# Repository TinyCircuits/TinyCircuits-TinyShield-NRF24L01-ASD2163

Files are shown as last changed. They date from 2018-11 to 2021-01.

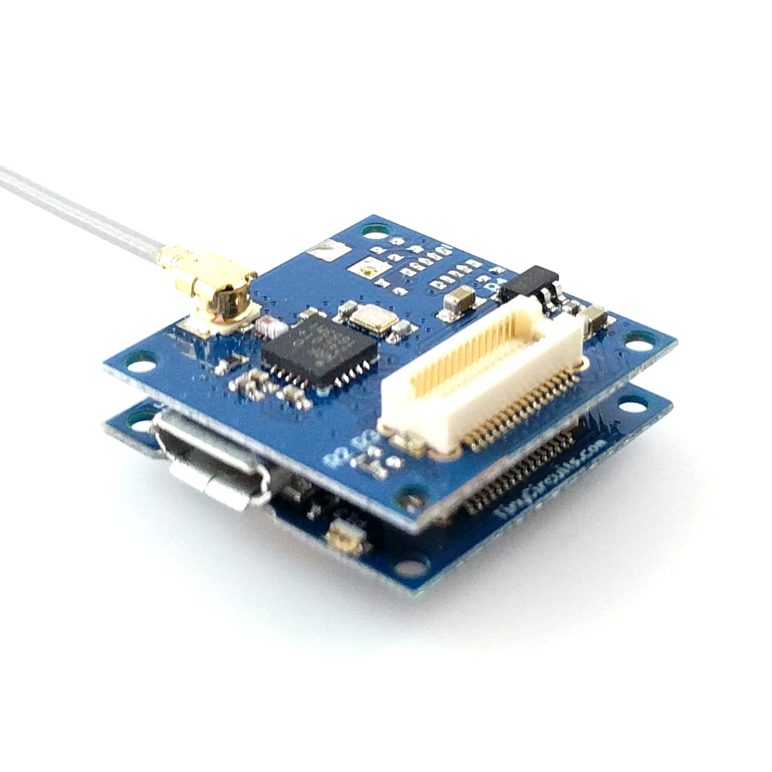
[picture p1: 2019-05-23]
images/ASD2163-R-Tutorial-Image-03.jpg

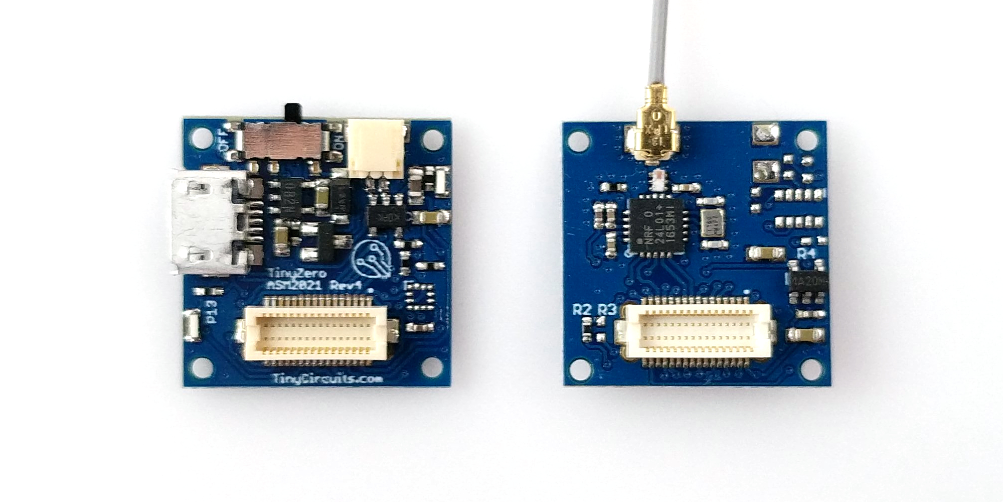
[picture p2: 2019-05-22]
images/ASD2163-R-Tutorial-Image-02.jpg

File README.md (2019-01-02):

# TinyCircuits TinyShield NRF24L01+ Radio Board
# ASD2613 Rev3

These are the design files for the TinyCircuits ASD2163 Rev3 PCB.  This is a TinyShield board that has a Nordic Semiconductor NRF24L01+ 2.4GHZ  chipset, local power supply and level shifters to connect between the TinyDuino and the radio transceiver. 

Format is in Cadsoft Eagle format - Eagle version 6.2 was used for the original design.

For more infomation on this, check out the product page at TinyCircuits.com:  https://tinycircuits.com/products/nrf24-2-4ghz-radio-tinyshieldc.html

# License:

Design by TinyCircuits.
All design files are released under the Creative Commons Attribution Share-Alike 3.0 License, see the following link for details: http://creativecommons.org/licenses/by-sa/3.0

All text above must be included in any redistribution or derived design

This project uses designs and concepts developed as part of the Arduino project and the LilyPad project.  The TinyCircuits design files themselves (schematics, PCB and libraries) are not directly derived from these works' design files and have been created new, however the concepts and basic architecture behind the TinyDuino and TinyLily products are derived and we thank the hard work of the organizations below for their contributions to open-source hardware:
  
Original Arduino Uno Design by Team Arduino

LilyPad Arduino Design by Leah Buechley and Sparkfun Electronics

Please support the open-source hardware community

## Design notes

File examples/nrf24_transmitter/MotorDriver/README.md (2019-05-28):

# TinyCircuits Dual Motor Driver Arduino Library

This library is intended for use with TinyCircuits' ASD2302 Dual Motor Driver TinyShield and ASD2303 Servo Controller Tinyshield. These shields use a ATtiny841 microcontroller with firmware that allows the 16 bit PWM outputs to be controlled through I2c. The Arduino library itself allows for easy interface using the TinyDuino platform. Included with the library is the ATtiny841 firmware- it is intended to be hackable and allow for extra functionality to be implemented(full ATtiny register access through I2C).

## Basic Example

Example programs are included that show how to drive motors or servos from the TinyDuino.

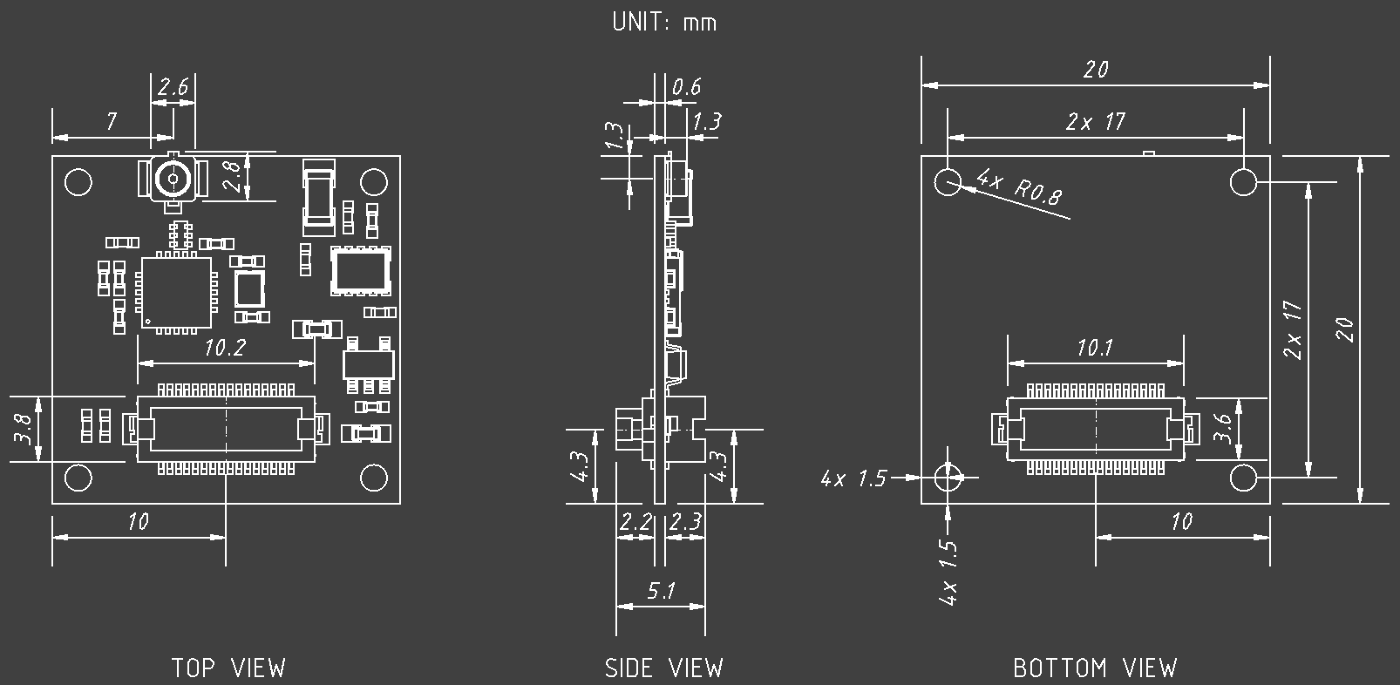
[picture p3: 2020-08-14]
cad/TinyShield_NRF24L01_ASD2163_REV3-DETAILED_DRAWING_COMPACT-PNG.png

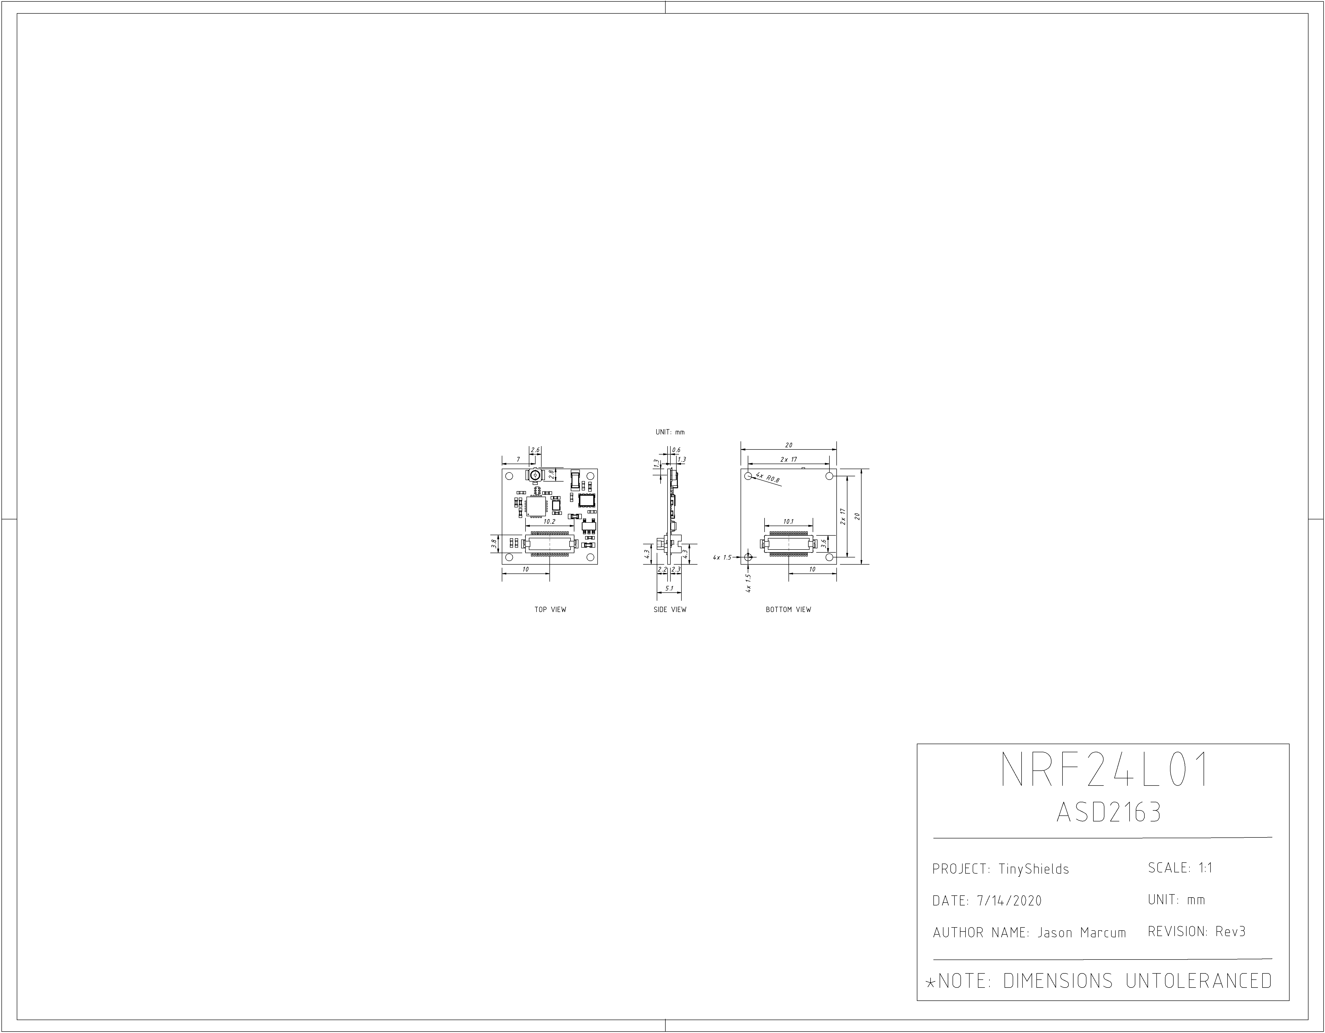
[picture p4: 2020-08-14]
cad/TinyShield_NRF24L01_ASD2163_REV3-DETAILED_DRAWING-PNG.png

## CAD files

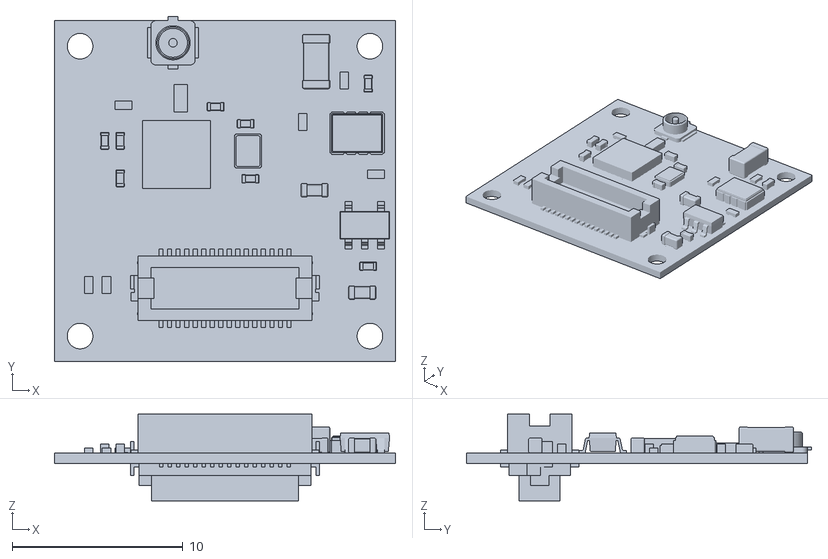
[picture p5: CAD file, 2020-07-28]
cad/TinyShield_NRF24L01_ASD2163_REV3-STL.stl
20.0 x 20.2 x 5.10

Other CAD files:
cad/TinyShield_NRF24L01_ASD2163_REV3-DETAILED_DRAWING-DXF.dxf

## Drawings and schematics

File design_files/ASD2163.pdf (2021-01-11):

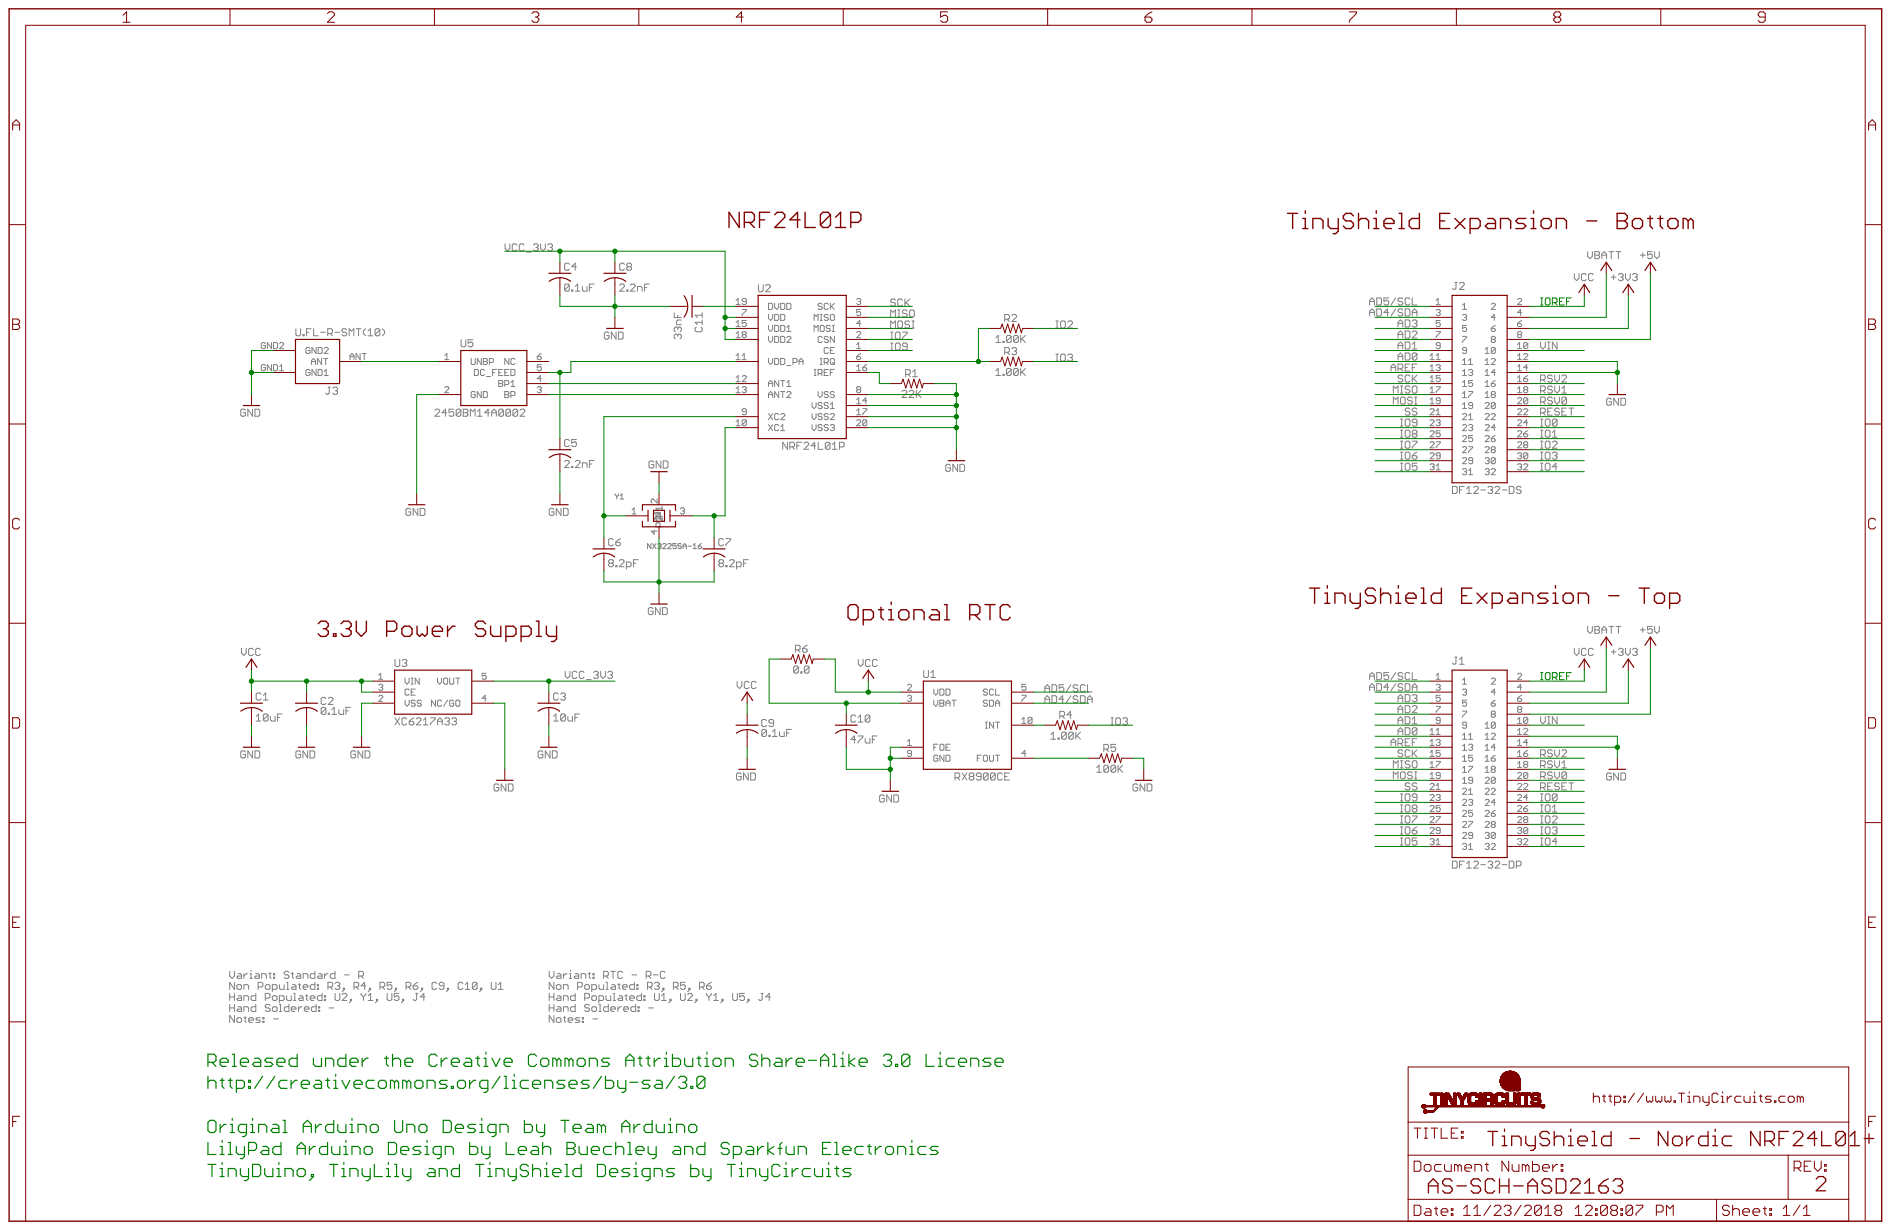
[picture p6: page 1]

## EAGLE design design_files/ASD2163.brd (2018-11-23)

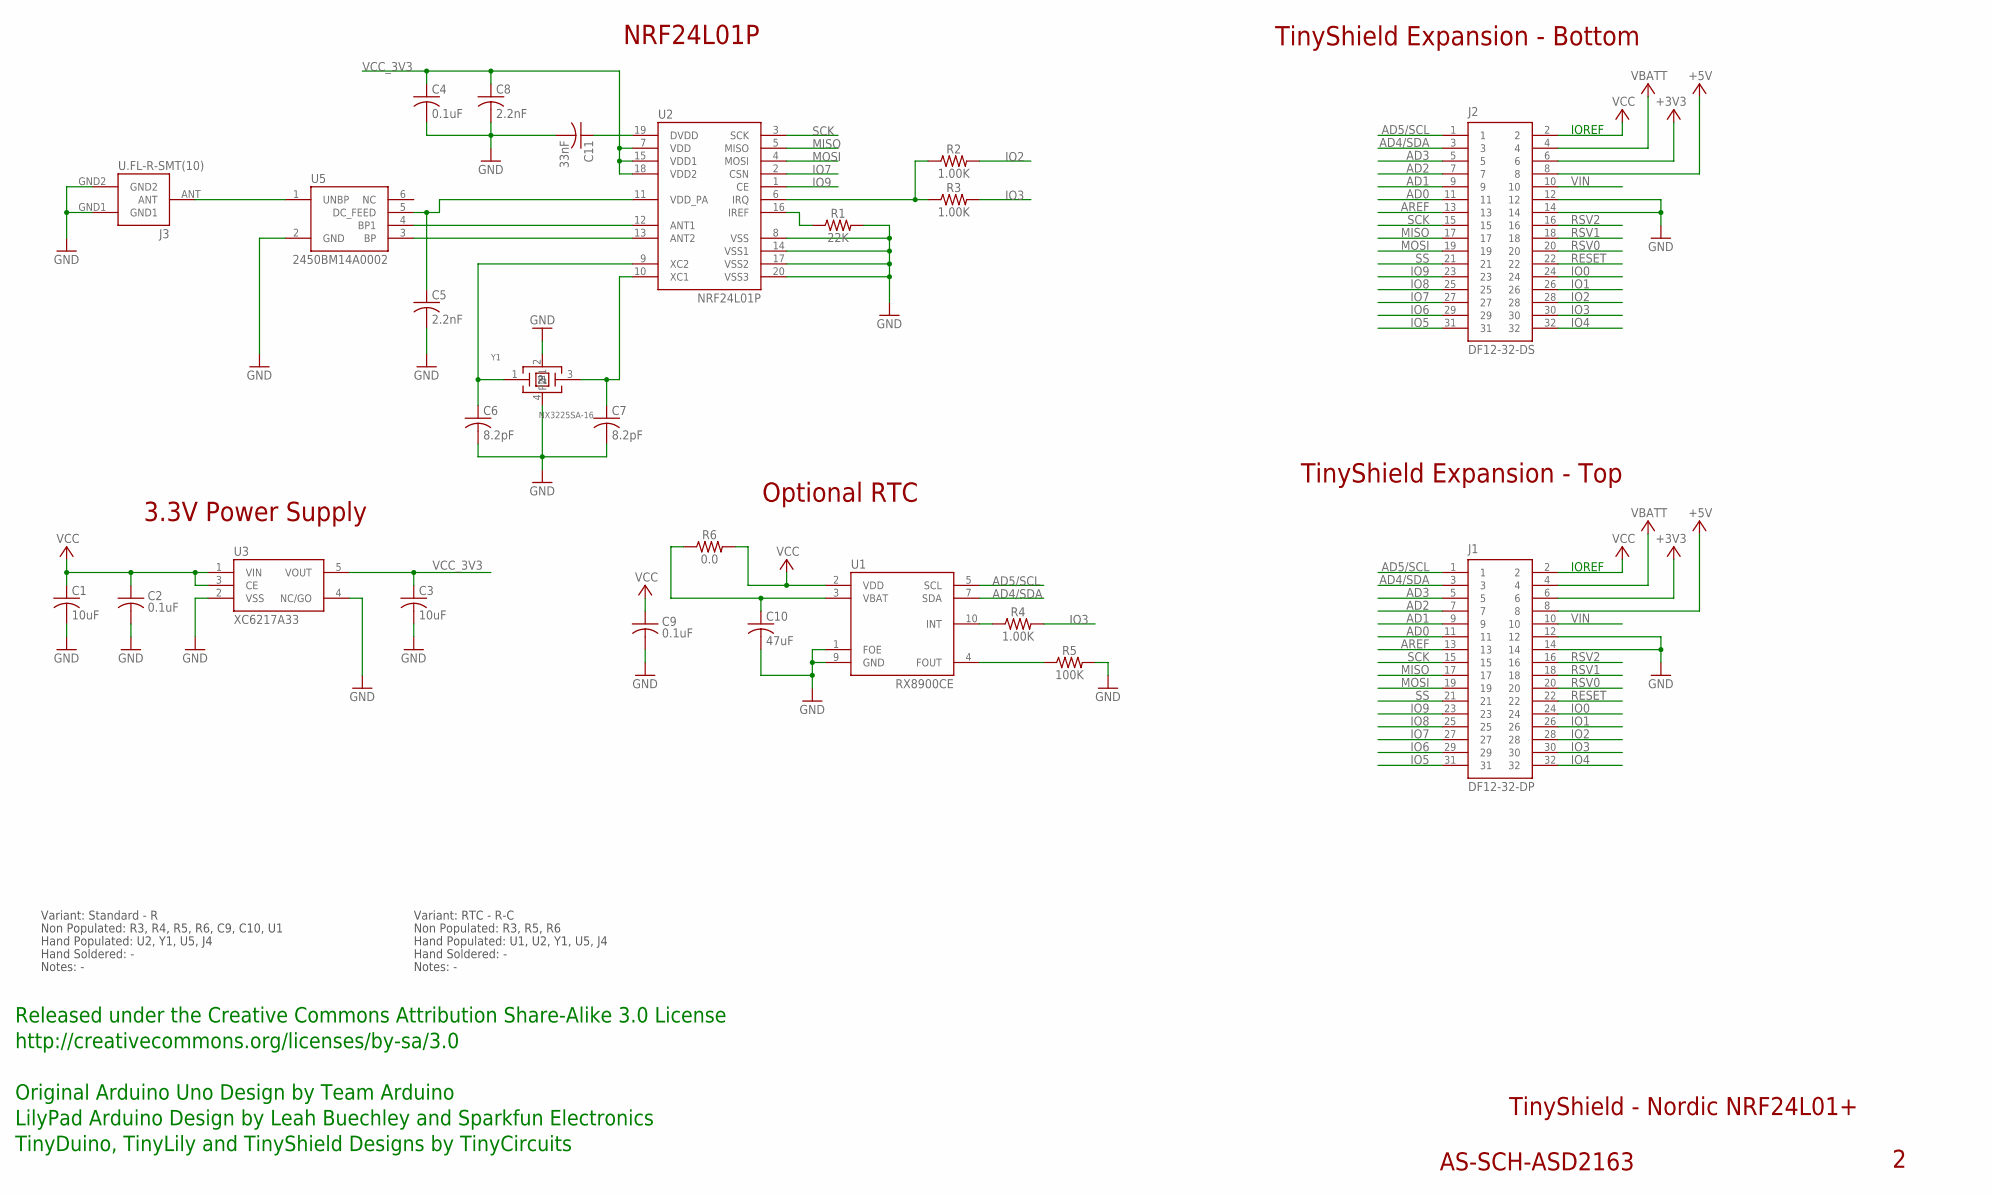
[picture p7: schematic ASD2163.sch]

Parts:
C1, C3: 10uF; C0603; PARTNO AS-ITM-00002
C2, C4, C9: 0.1uF; C0402; PARTNO AS-ITM-00008
C5: 2.2nF; C0402
C6, C7: 8.2pF; C0402; PARTNO AS-ITM-00247
C8: 2.2nF; C0402; PARTNO AS-ITM-00085
C10: 47uF; C1206
C11: 33nF; C0402; PARTNO AS-ITM-00248
J1: DF12-32-DP; PARTNO AS-ITM-00015
J2: DF12-32-DS; PARTNO AS-ITM-00012
J3: U.FL-R-SMT(10)
R1: 22K; 0402
R2, R3, R4: 1.00K; 0402; PARTNO AS-ITM-00003
R5: 100K; 0402
R6: 0.0; 0402; PARTNO AS-ITM-00076
U1: RX8900CE
U2: NRF24L01P; QFN20-NO_PAD
U3: XC6217A33; SOT-25; PARTNO AS-ITM-00249
U5: 2450BM14A0002
Y1: NX3225SA-16; ABM11; PARTNO AS-ITM-00228

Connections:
+3V3: J1.6, J2.6
+5V: J1.8, J2.8
AD0: J1.11, J2.11
AD1: J1.9, J2.9
AD2: J1.7, J2.7
AD3: J1.5, J2.5
AD4/SDA: J1.3, J2.3, U1.7 (SDA)
AD5/SCL: J1.1, J2.1, U1.5 (SCL)
AREF: J1.13, J2.13
GND: C1.2, C2.2, C3.2, C4.2, C5.2, C6.2, C7.2, C8.2, C9.2, C10.2, C11.2, J1.12, J1.14, J2.12, J2.14, J3.GND1, J3.GND2, R1.2, R5.2, U1.1 (FOE), U1.9 (GND), U2.8 (VSS), U2.14 (VSS1), U2.17 (VSS2), U2.20 (VSS3), U3.2 (VSS), U3.4 (NC/GO), U5.2 (GND), Y1.2, Y1.4 (P1)
IO0: J1.24, J2.24
IO1: J1.26, J2.26
IO2: J1.28, J2.28, R2.2
IO3: J1.30, J2.30, R3.2, R4.2
IO4: J1.32, J2.32
IO5: J1.31, J2.31
IO6: J1.29, J2.29
IO7: J1.27, J2.27, U2.2 (CSN)
IO8: J1.25, J2.25
IO9: J1.23, J2.23, U2.1 (CE)
MISO: J1.17, J2.17, U2.5 (MISO)
MOSI: J1.19, J2.19, U2.4 (MOSI)
unnamed: R1.1, U2.16 (IREF)
unnamed: C6.1, U2.9 (XC2), Y1.1
unnamed: J3.ANT, U5.1 (UNBP)
unnamed: C10.1, R6.1, U1.3 (VBAT)
unnamed: C11.1, U2.19 (DVDD)
unnamed: U2.13 (ANT2), U5.3 (BP)
unnamed: U2.12 (ANT1), U5.4 (BP1)
unnamed: C5.1, U2.11 (VDD_PA), U5.5 (DC_FEED)
unnamed: C7.1, U2.10 (XC1), Y1.3 (2)
unnamed: R5.1, U1.4 (FOUT)
RDYN: R2.1, R3.1, U2.6 (IRQ)
RDYN1: R4.1, U1.10 (INT)
RESET: J1.22, J2.22
RSV0: J1.20, J2.20
RSV1: J1.18, J2.18
RSV2: J1.16, J2.16
SCK: J1.15, J2.15, U2.3 (SCK)
SS: J1.21, J2.21
VBATT: J1.4, J2.4
VCC: C1.1, C2.1, C9.1, J1.2, J2.2, R6.2, U1.2 (VDD), U3.1 (VIN), U3.3 (CE)
VCC_3V3: C3.1, C4.1, C8.1, U2.7 (VDD), U2.15 (VDD1), U2.18 (VDD2), U3.5 (VOUT)
VIN: J1.10, J2.10

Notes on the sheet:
TinyShield Expansion - Bottom
TinyShield - Nordic NRF24L01+
AS-SCH-ASD2163
TinyShield Expansion - Top
IOREF
Released under the Creative Commons Attribution Share-Alike 3.0 License
http://creativecommons.org/licenses/by-sa/3.0
LilyPad Arduino Design by Leah Buechley and Sparkfun Electronics
TinyDuino, TinyLily and TinyShield Designs by TinyCircuits
Original Arduino Uno Design by Team Arduino
3.3V Power Supply
NRF24L01P
Optional RTC
Non Populated: R3, R4, R5, R6, C9, C10, U1
Hand Populated: U2, Y1, U5, J4
Hand Soldered: -
Notes: -
Variant: Standard - R
Non Populated: R3, R5, R6
Hand Populated: U1, U2, Y1, U5, J4
Variant: RTC - R-C

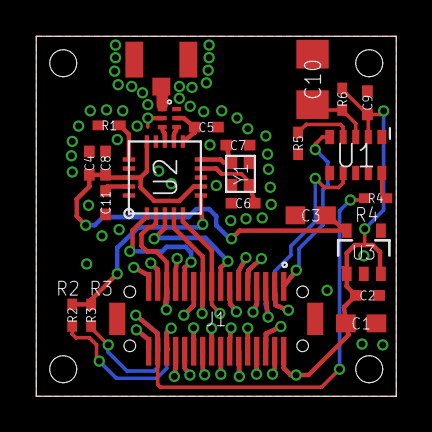
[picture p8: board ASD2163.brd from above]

Board: 2 copper layers, 20.0 x 20.0 mm, 26 parts (1 on the bottom side), 44 nets.

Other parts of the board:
U$1: DOCFIELD-TINYCIRCUITS-PCB

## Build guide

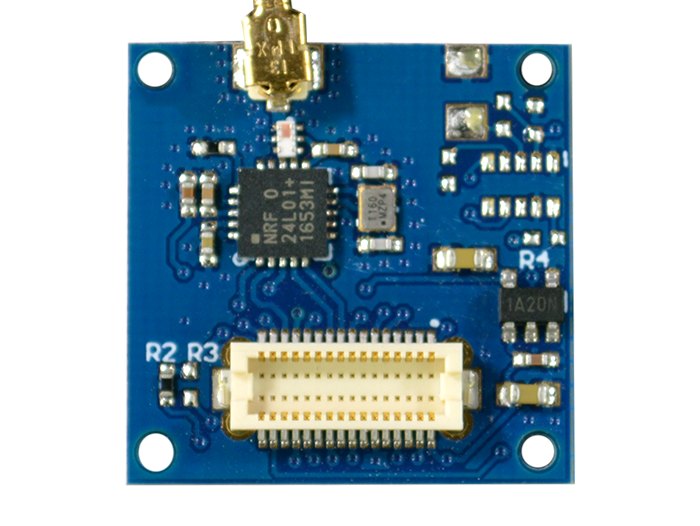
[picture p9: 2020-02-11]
images/ASD2163-R-Tutorial-Image-01.png

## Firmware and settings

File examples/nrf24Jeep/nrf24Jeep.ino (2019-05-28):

#define use433 0


#include <Wire.h>
#include <SPI.h>
#include <RH_NRF24.h>
#include <RH_RF22.h>
#include "RTIMUSettings.h"
#include "RTIMU.h"
#include "RTFusionRTQF.h"
#include "CalLib.h"

RTIMU *imu;                                           // the IMU object
RTFusionRTQF fusion;                                  // the fusion object
RTIMUSettings settings;                               // the settings object


#include <MotorDriver.h>
#include <ServoDriver.h>

MotorDriver motor(NO_R_REMOVED);
ServoDriver servo(R1_REMOVED);

#if(use433)
RH_RF22 nrf24(7, 3);
#else
RH_NRF24 nrf24(9, 7);
#endif

long timeout = 1000;
long lastcommand = 0;

int servoHold = 2000;
int servoRelease = 1000;

int maxPWM = 500;

#if defined (ARDUINO_ARCH_AVR)
#define SerialMonitorInterface Serial
#elif defined(ARDUINO_ARCH_SAMD)
#define SerialMonitorInterface SerialUSB
#endif


void setup()
{
  SerialUSB.begin(115200);
  //while (!SerialUSB);
  Wire.begin();

#if(use433)
  nrf24.init();
  nrf24.setTxPower(RH_RF22_TXPOW_20DBM);
  nrf24.setModemConfig(RH_RF22::GFSK_Rb125Fd125);//GFSK_Rb4_8Fd45?
#else
  nrf24.init();
  nrf24.setChannel(1);
  nrf24.setRF(RH_NRF24::DataRate250kbps, RH_NRF24::TransmitPower0dBm);
#endif


  if ( motor.begin(500)) {
    SerialMonitorInterface.println("Motor driver not detected!");
    //while (1);
  }
  motor.setMotor(1, 0);
  motor.setMotor(2, 0);
  if (servo.begin(20000)) {    //Set the period to 20000us or 20ms, correct for driving most servos
    SerialMonitorInterface.println("Servo driver not detected!");
    //while (1);
  }
  servo.begin(5000);
  servo.setServo(1, 1500);

  /*
    Wire.beginTransmission(0x70);
    Wire.write(0x04 + 0);
    Wire.endTransmission();
  */
  motor.setFailsafe(100);
  imu = RTIMU::createIMU(&settings);
  imu->IMUInit();
  fusion.setGyroEnable(true);
  fusion.setAccelEnable(true);
}

int currentXdata = 0;
int currentYdata = 0;

int setPoint = 512;
int in = 0;
int lastPWM = 0;

void loop()
{
  if (imu->IMURead()) {                                // get the latest data if ready yet
    fusion.newIMUData(imu->getGyro(), imu->getAccel(), imu->getCompass(), imu->getTimestamp());
    currentXdata = fusion.getFusionPose().x() * RTMATH_RAD_TO_DEGREE;
    currentYdata = -fusion.getFusionPose().y() * RTMATH_RAD_TO_DEGREE;
    //SerialUSB.print(currentXdata);
    //SerialUSB.print('\t');
    //SerialUSB.println(currentYdata);
    
  }
  if (nrf24.available())
  {
    // Should be a message for us now
    uint8_t buf[32];
    uint8_t len = sizeof(buf);
    if (nrf24.recv(buf, &len) && buf[0] == 5)
    {
      lastcommand = millis();
      int16_t LY = buf[1] << 8 | buf[2];
      int16_t RY = buf[3] << 8 | buf[4];
      int16_t LX = buf[5] << 8 | buf[6];
      int16_t RX = buf[7] << 8 | buf[8];

      if (abs(LY) < 50) {
        LY = 0;
      }
      //motor.setMotor(1, constrain(-LY, -500, 500));
      servo.setServo(1, 1500 - 75 + constrain(1.1 * -(float)RX, -600, 500));

      motor.setMotor(1, constrain(-RY, -500, 500));
      motor.setMotor(2, constrain(LY, -500, 500));


      int voltage = getVCClevel();
      uint8_t data[8];
      data[0] = 5;
      data[1] = abs(0);
      data[2] = voltage >> 8;
      data[3] = voltage;
      data[4] = currentXdata >> 8;
      data[5] = currentXdata;
      data[6] = currentYdata >> 8;
      data[7] = currentYdata;
      nrf24.send(data, 8);
      nrf24.waitPacketSent();
      nrf24.sleep();
    }
  }
  if (millis() > lastcommand + timeout) {
    //digitalWrite(13,LOW);
    motor.setMotor(1, 0);
    motor.setMotor(2, 0);
    lastcommand = millis();
  }

}

int getVCClevel() {
  //http://forum.arduino.cc/index.php?topic=133907.0
  const long InternalReferenceVoltage = 1100L;
  /*ADMUX = (0<<REFS1) | (1<<REFS0) | (0<<ADLAR) | (1<<MUX3) | (1<<MUX2) | (1<<MUX1) | (0<<MUX0);
    delay(1);
    ADCSRA |= _BV( ADSC );
    while( ( (ADCSRA & (1<<ADSC)) != 0 ) );
    int result = (((InternalReferenceVoltage * 1024L) / ADC) + 5L) / 10L;*/
  return 1;//this should be in hundredths of a volt
}

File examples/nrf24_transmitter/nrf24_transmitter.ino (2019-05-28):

#define use433 0

#include <Wire.h>
#include <SPI.h>
#include <RH_NRF24.h>
#include <RH_RF22.h>
#include <TinyScreen.h>

#define	BLACK           0x00
#define	BLUE            0xE0
#define	RED             0x03
#define	GREEN           0x1C
#define	DGREEN           0x0C
#define YELLOW          0x1F
#define WHITE           0xFF
#define ALPHA           0xFE
#define	BROWN           0x32

TinyScreen display = TinyScreen(TinyScreenPlus);


#if(use433==1)
RH_RF22 nrf24(7, 3);
#else
RH_NRF24 nrf24(9, 7);
#endif


int RX = 0;
int RY = 0;
int LX = 0;
int LY = 0;
int RX_center = 0;
int RY_center = 0;
int LX_center = 0;
int LY_center = 0;
byte leftButton = 0;
byte rightButton = 0;
byte firstRun = 1;

const int amtAverage = 30;
int avgIndex = 0;
float average[amtAverage];

void setup()
{
  pinMode(4, OUTPUT);
  digitalWrite(4, HIGH);
  Serial.begin(9600);
  Wire.begin();
  display.begin();
  display.setBrightness(5);
  display.setFont(liberationSansNarrow_8ptFontInfo);
  display.setCursor(0, 0);
  display.print("RSSI: ");
  display.setCursor(0, 10);
  display.print("Voltage: ");
  display.setCursor(0, 20);
#if(use433==1)
  nrf24.init();
  nrf24.setTxPower(RH_RF22_TXPOW_20DBM);
  nrf24.setModemConfig(RH_RF22::GFSK_Rb125Fd125);//GFSK_Rb4_8Fd45?
#else
  nrf24.init();
  nrf24.setChannel(1);
  nrf24.setRF(RH_NRF24::DataRate250kbps, RH_NRF24::TransmitPower0dBm);
#endif
  display.drawLine(28, 47, 67, 47, WHITE);
}

void loop()
{
  uint8_t data[10];//transmit data
  getJoystick();//update joystick position variables
  if (0) {
    pinMode(5, OUTPUT);
    digitalWrite(5, HIGH);
    LX = -(analogRead(3) - 512) - 75;
    LY = -(analogRead(2) - 512) - 50;
    RX = (-(analogRead(0) - 512) + 25 - 78);
    RY = -(analogRead(1) - 512) - 50;

  }
  if (0) {
    //LY = map(analogRead(1), 260, 425, -500, 500) + 60 + 20;
    //RX = map(analogRead(0), 322, 608, -500, 500);
    RX = map(analogRead(1), 470, 860, -300, 300) + 35;
    LY = map(analogRead(0), 360, 602, -500, 500);
    // LY = analogRead(0);
    //RX = analogRead(1);

  }
  if (0) {
    //RY=-RY;
    //LX=LY;
    LX=RY;
    RY=-LY;
  }
  if (0) {
    //RY=-RY;
    //LX=LY;
    LY=-LY;
    RX=RX;
  }
  if (1) {
    //RY=-RY;
    //LX=LY;
    //LY=-LY;
    RY=RX;
  }
  /*SerialUSB.print(LX);
    SerialUSB.print('\t');
    SerialUSB.print(LY);
    SerialUSB.print('\t');
    SerialUSB.print(RX);
    SerialUSB.print('\t');
    SerialUSB.print(RY);
    SerialUSB.println();
  */
  SerialUSB.print(LY);
  SerialUSB.print('\t');
  SerialUSB.print(RX);
  SerialUSB.println();
  data[0] = 5;
  data[1] = LY >> 8; //pack integer data into bytes
  data[2] = LY;
  data[3] = RY >> 8;
  data[4] = RY;
  data[5] = LX >> 8; //pack integer data into bytes
  data[6] = LX;
  data[7] = RX >> 8;
  data[8] = RX;
  data[9] = leftButton;
  
  nrf24.send(data, 10);
  nrf24.waitPacketSent();

  uint8_t buf[RH_NRF24_MAX_MESSAGE_LEN];
  uint8_t len = sizeof(buf);

  if (nrf24.waitAvailableTimeout(50))
  {
    if (nrf24.recv(buf, &len) && buf[0] == 5)
    {
      uint16_t voltage = buf[2] << 8 | buf[3];
      int16_t x = buf[4] << 8 | buf[5];
      int16_t y = buf[6] << 8 | buf[7];
      Serial.println(x);
      display.setCursor(75, 0);
      display.print(0 - buf[1]);
      display.print("  ");
      display.setCursor(75, 10);
      average[avgIndex++] = voltage / 100.0;
      if (avgIndex >= amtAverage)avgIndex = 0;
      float temp = 0.0;
      for (int i = 0; i < amtAverage; i++) {
        temp += average[i];
      }
      temp /= (float)amtAverage;

      display.print(temp);
      display.print("  ");
      x = constrain(x, -45, 45) / 3;
      y = constrain(y, -45, 45) / 3;
      display.clearWindow(32, 32, 32, 32);
      //display.drawLine(0,47+x,31,47-x,WHITE);
      display.drawLine(32, constrain(47 + y + x, 32, 63), 63, constrain(47 - y + x, 32, 63), WHITE);

    }
    nrf24.recv(buf, &len);
  }
  delay(10);
}

void getJoystick() {
  Wire.requestFrom(0x22, 6);
  int data[4];
  for (int i = 0; i < 4; i++) {
    data[i] = Wire.read();
  }
  byte lsb = Wire.read();
  byte buttons = ~Wire.read();
  leftButton = buttons & 4;
  rightButton = buttons & 8;
  for (int i = 0; i < 4; i++) {
    data[i] <<= 2;
    data[i] |= ((lsb >> (i * 2)) & 3);
    data[i] -= 511;
  }
  RY = data[0]; //was RX
  RX = -data[1]; //was RY
  LX = -data[2];
  LY = data[3];
}

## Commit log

2019-01-02 update format
    [ASD2163.brd, ASD2163.sch]
2019-05-28 added examples and libraries
    [project.cfg]
2020-07-28 Add CAD data
    [TinyShield_NRF24L01_ASD2163_REV3-DETAILED_DRAWING-DXF.dxf, TinyShield_NRF24L01_ASD2163_REV3-STL.stl]
2020-08-14 Update CAD drawing
    [TinyShield_NRF24L01_ASD2163_REV3-DETAILED_DRAWING-DXF.dxf]
2021-01-11 fix the schematic
